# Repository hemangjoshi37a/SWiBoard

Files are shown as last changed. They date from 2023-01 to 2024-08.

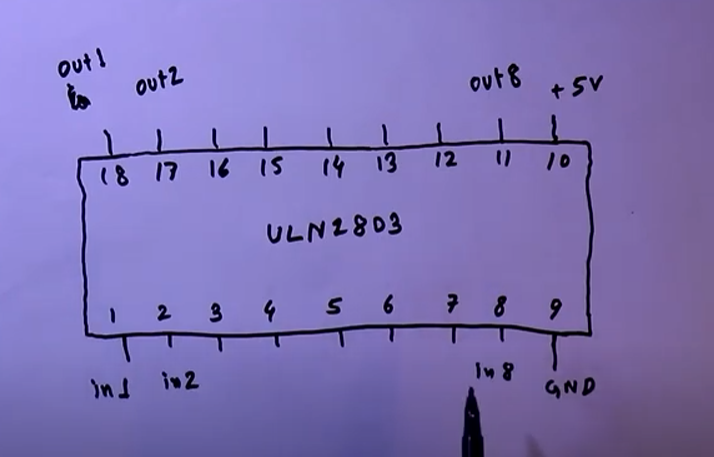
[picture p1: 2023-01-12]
ULN2803_PINOUT.PNG

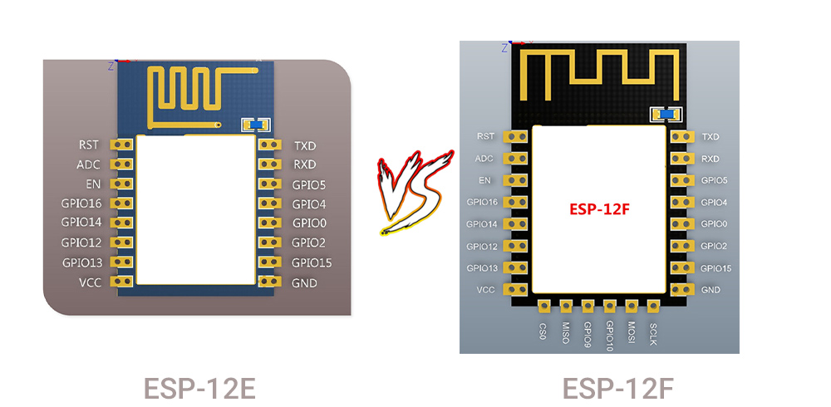
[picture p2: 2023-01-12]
ESP12F_VS_ESP12E_PINOUT.jpg

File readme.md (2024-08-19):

# 🏠 SWiBoard: Revolutionize Your Home with Smart WiFi Switch Control

  

> Transform your living space into a smart home paradise with SWiBoard - Where convenience meets innovation!

SWiBoard - Smart WiFi Switch Board Converter

## 🚀 Embrace the Future of Home Automation with SWiBoard

Are you ready to step into the future of home automation? SWiBoard is your gateway to a smarter, more connected living space. Our cutting-edge Tasmota IoT WiFi switch board converter seamlessly transforms your ordinary switches into powerful smart controls, putting the power of home automation right at your fingertips.

### 🌟 Unleash the Power of Smart Home Technology

- **Effortless Installation**: Upgrade your home without the hassle of complex rewiring
- **Global Control**: Manage your entire home from anywhere in the world with your smartphone
- **Voice-Activated Convenience**: Compatible with Amazon Alexa and Google Assistant for hands-free control
- **Versatile Connectivity**: Support for MQTT, HTTP, and more protocols ensures maximum compatibility
- **Budget-Friendly Innovation**: Experience the benefits of a smart home without breaking the bank

## 📱 SWiBoard Android App: Your Smart Home Command Center

Take charge of your smart home ecosystem with our intuitive, Flutter-powered Android app. Experience seamless control across all your devices with a user-friendly interface designed for both beginners and tech enthusiasts.

| Home Screen | Device Control | Settings | Customization | MQTT Setup |
|:-:|:-:|:-:|:-:|:-:|
| Home | Control | Settings | Customize | MQTT |

### 🛠️ Powerful Features at Your Fingertips

- **Centralized Device Management**: Control all your SWiBoard devices from a single, intuitive dashboard
- **Real-Time Responsiveness**: Experience instant status updates for precise control
- **User-Centric Design**: Navigate effortlessly with our thoughtfully crafted interface
- **Robust MQTT Integration**: Enjoy reliable, low-latency communication for seamless operation
- **Personalization Options**: Tailor your smart home experience with custom device names and icons

## 💡 Why SWiBoard is the Smart Choice for Your Home

1. **Seamless Integration**: Perfectly adapts to your existing electrical infrastructure
2. **Scalable Smart Home Solution**: Start small and expand your smart home ecosystem at your own pace
3. **Energy Optimization**: Monitor and reduce your power consumption for a greener home
4. **Enhanced Home Security**: Simulate occupancy by controlling lights remotely
5. **Future-Ready Technology**: Regular updates keep you at the forefront of smart home innovation

## 🔧 Technical Prowess Meets User-Friendly Design

- **Universal Compatibility**: Works flawlessly with most standard switch boxes
- **Reliable Connectivity**: Utilizes stable WiFi 2.4GHz technology
- **Flexible Power Options**: Supports AC 100-240V for global use
- **Cross-Platform App Support**: Compatible with Android 5.0+ and iOS 10.0+
- **Diverse Protocol Support**: Harness the power of MQTT, HTTP, and CoAP for ultimate flexibility

## 📦 Unboxing Your Smart Home Future

- SWiBoard WiFi Switch Converter: The heart of your smart home transformation
- Comprehensive Installation Guide: Step-by-step instructions for a smooth setup
- Mounting Hardware: Everything you need for a secure installation
- Professional-Grade Wire Connectors: Ensure safe and reliable electrical connections

## 🛠️ From Traditional to Smart: Your Installation Journey

1. Safety First: Power down at the circuit breaker
2. Out with the Old: Remove your existing switch plate
3. Smart Connections: Wire up your SWiBoard following our detailed diagram
4. Secure Integration: Mount SWiBoard firmly in your switch box
5. Power Up: Restore electricity and connect to your home WiFi
6. App Magic: Download the SWiBoard app and bring your smart switch to life!

## 📱 Embark on Your SWiBoard App Adventure

### Project Anatomy

```
swiboard/
├── lib/               # Core Dart code
│   ├── main.dart      # Application entry point
│   ├── screens/       # UI screen implementations
│   ├── widgets/       # Reusable UI components
│   └── services/      # Business logic and data management
├── android/           # Android-specific configurations
├── ios/               # iOS-specific setups
├── assets/            # Static resources (images, fonts)
└── test/              # Automated tests for robust performance
```

### Quick Start Guide

1. Prepare Your Environment: Ensure Flutter is properly installed
2. Clone the Innovation: `git clone https://github.com/hemangjoshi37a/swiboard.git`
3. Navigate to the Future: `cd swiboard`
4. Gather the Essentials: `flutter pub get`
5. Launch into Smart Home Control: `flutter run`

### Crafting Your Smart Home App

- For Android Enthusiasts: `flutter build apk`
- For iOS Aficionados: `flutter build ios` (Xcode required on macOS)

## 🔗 Your Gateway to Smart Living

- [🛒 Acquire SWiBoard](https://hjlabs.in/product/swiboard-wifi-switch-board-iot-device/)
- [📱 SWiBoard App Download](https://play.google.com/store/apps/details?id=in.hjlabs.swiboard)
- [🎨 Explore SWiBoard's 3D Design](https://grabcad.com/library/swiboard-tasmota-iot-wifi-switch-board-converter-1)
- [🎥 Witness SWiBoard in Action](https://youtu.be/BrakSGmQZB8)

## 📫 Connect with the Mastermind Behind SWiBoard

[](https://wa.me/917016525813) &nbsp;
[](https://t.me/hjlabs) &nbsp;
[](mailto:hemangjoshi37a@gmail.com) &nbsp;
[](https://www.linkedin.com/in/hemang-joshi-046746aa) &nbsp;
[](https://www.facebook.com/hemangjoshi37) &nbsp;
[](https://twitter.com/HemangJ81509525) &nbsp;
[](https://www.tumblr.com/blog/hemangjoshi37a-blog) &nbsp;
[](https://stackoverflow.com/users/8090050/hemang-joshi) &nbsp;
[](https://www.instagram.com/hemangjoshi37) &nbsp;
[](https://in.pinterest.com/hemangjoshi37a) &nbsp;
[](http://hemangjoshi.blogspot.com) &nbsp;
[](https://hjlabs.in/) &nbsp;
[](https://gitlab.com/hemangjoshi37a) &nbsp;

## 🚀 Dive into a World of Innovation

Explore more groundbreaking projects that are shaping the future of technology:

- [pyPortMan](https://github.com/hemangjoshi37a/pyPortMan): Revolutionizing port management
- [transformers_stock_prediction](https://github.com/hemangjoshi37a/transformers_stock_prediction): AI-powered stock market insights
- [TrendMaster](https://github.com/hemangjoshi37a/TrendMaster): Stay ahead of market trends
- [hjAlgos_notebooks](https://github.com/hemangjoshi37a/hjAlgos_notebooks): A treasure trove of algorithmic wisdom
- [AutoCut](https://github.com/hemangjoshi37a/AutoCut): Streamlining video editing workflows
- [My_Projects](https://github.com/hemangjoshi37a/My_Projects): A showcase of diverse tech innovations
- [Arduino and ESP8266 Wonders](https://github.com/hemangjoshi37a/my_Arduino): Pushing the boundaries of IoT
- [TelegramTradeMsgBacktestML](https://github.com/hemangjoshi37a/TelegramTradeMsgBacktestML): Where finance meets machine learning

## 🤝 Join the Smart Home Revolution

Your insights and contributions can help shape the future of SWiBoard! Whether you're squashing bugs, enhancing documentation, or dreaming up new features, your input is invaluable. Don't hesitate to submit pull requests or raise issues for any improvements you envision.

## 📄 Open Source Commitment

SWiBoard is proudly open source, licensed under the MIT License. For full details, refer to the [LICENSE](LICENSE) file in our repository.

---

<p align="center">
  <i>Embark on your smart home journey with SWiBoard - Where every switch is a step into the future!</i>
</p>

<p align="center">
  <a href="https://hjlabs.in/product/swiboard-wifi-switch-board-iot-device/">🏠 Acquire SWiBoard</a> •
  <a href="https://play.google.com/store/apps/details?id=in.hjlabs.swiboard">📱 Get the App</a> •
  <a href="https://github.com/hemangjoshi37a/swiboard/issues">🐛 Report Issues</a> •
  <a href="https://github.com/hemangjoshi37a/swiboard/issues">✨ Suggest Features</a>
</p>

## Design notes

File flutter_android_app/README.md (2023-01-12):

# swiboard

Your Own WiFi Switch Board Converter

The SWiBoard is a versatile Tasmota IoT WiFi switch board converter that allows you to easily convert your traditional switches into smart, WiFi-enabled controls. With this device, you can control your lights and appliances remotely using your smartphone or voice commands through Amazon Alexa or Google Assistant. Its compact design and easy installation make it an ideal solution for both residential and commercial settings. Additionally, the SWiBoard supports various protocols such as MQTT, HTTP, and more, making it compatible with a wide range of home automation platforms. With the SWiBoard, you can enjoy the convenience and flexibility of smart home technology without the need for expensive and complex rewiring.

- [Buy Now on hjLabs.in](https://hjlabs.in/product/swiboard-wifi-switch-board-iot-device/)
- [SWiBoard App :Tasmota MQTT Control](https://play.google.com/store/apps/details?id=in.hjlabs.swiboard)
- [SWiBoard 3D Design on GrabCAD](https://grabcad.com/library/swiboard-tasmota-iot-wifi-switch-board-converter-1)

## Social Media :
*  [WhatsApp/917016525813](https://wa.me/917016525813)
*  [Telegram/hjlabs](https://t.me/hjlabs)
* [ Gmail/hemangjoshi37a@gmail.com](mailto:hemangjoshi37a@gmail.com)
* [ Facebook/hemangjoshi37](https://www.facebook.com/hemangjoshi37/)
* [ Twitter/HemangJ81509525](https://twitter.com/HemangJ81509525)
*  [LinkedIn/hemang-joshi-046746aa](https://www.linkedin.com/in/hemang-joshi-046746aa/)
*  [Tumblr/hemangjoshi37a-blog](https://www.tumblr.com/blog/hemangjoshi37a-blog)
*  [Pinterest/hemangjoshi37a](https://in.pinterest.com/hemangjoshi37a/)
*  [Blogger/hemangjoshi](http://hemangjoshi.blogspot.com/)
*  [Instagram/hemangjoshi37](https://www.instagram.com/hemangjoshi37/)

## Checkout Cool GitHub Other Repositories:
- [pyPortMan](https://github.com/hemangjoshi37a/pyPortMan)
- [transformers_stock_prediction](https://github.com/hemangjoshi37a/transformers_stock_prediction)
- [TrendMaster](https://github.com/hemangjoshi37a/TrendMaster)
- [hjAlgos_notebooks](https://github.com/hemangjoshi37a/hjAlgos_notebooks)
- [AutoCut](https://github.com/hemangjoshi37a/AutoCut)
- [My_Projects](https://github.com/hemangjoshi37a/My_Projects)
- [Cool Arduino and ESP8266 or NodeMCU Projects](https://github.com/hemangjoshi37a/my_Arduino)
- [Telegram Trade Msg Backtest ML](https://github.com/hemangjoshi37a/TelegramTradeMsgBacktestML)

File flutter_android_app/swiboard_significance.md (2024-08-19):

# SWiBoard - A Tasmota MQTT5 Flutter Firebase App

Your Own WiFi Switch Board

## The significance for SWiBoard App

### Why App when I have web access to tasmota device?

- For the most use cases one might not be under the same wifi network. And need remote access to the device from internet.

### I can easily forward port from my local network and can access it from internet. Then why App?

- One might not have access to static IP considering where one is living or may be very costly to have static IP. So we need MQTT5 for connecting device with internet.

### There are already many apps available on playstore for tasmota then why SWiBoard?

- Most if not all of them only use web socket to connect to tasmota device and not MQTT, and that's why they are not suitable for use from internet connection. Also configuring all the apps with tasmota device is quite tricky in some cases. But in SWiBoard you need to onyl enter the device topic of your tasmota device and it automatically configures your app and adds the device and UI componets of the configures device like switches and sliders and color selector etc.

- Also nice to have is we are using google firebase databse to store the configurations of the users so that if they somehow uninstall the app or change the device that all they need to do is just install the app and login with google account to get all the configuration back and don't need to reconfigure all the devices.

## Also in near future we are trying to give as many options as possible in the app to configure the device using MQTT5 to configure from the internet

## Here is the link to The app : [SWiBoard :Tasmota MQTT Control](https://play.google.com/store/apps/details?id=in.hjlabs.swiboard)

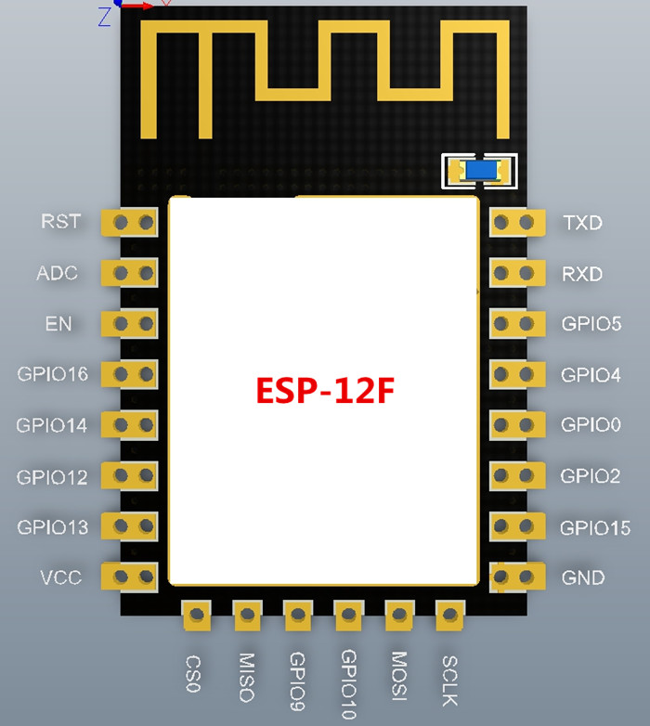
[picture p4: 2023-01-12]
esp12f_pinout.jpg

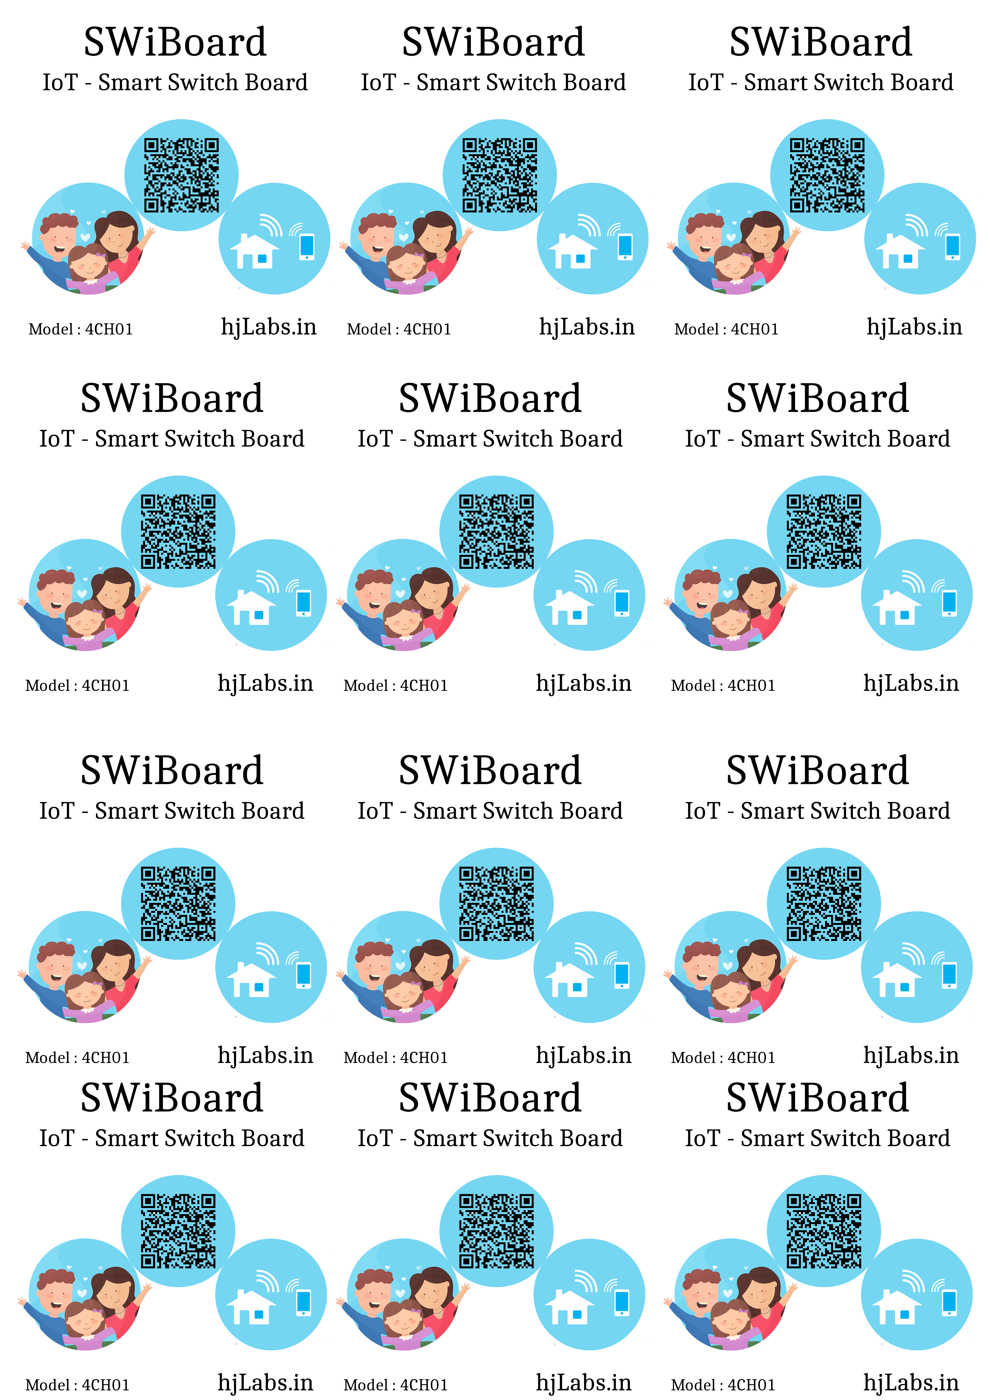
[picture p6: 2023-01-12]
Cover_sticker.png

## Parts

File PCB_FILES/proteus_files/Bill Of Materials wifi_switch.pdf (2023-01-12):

# Bill Of Materials for wifi_switch

Design Title | wifi_switch

## Author Document Number Revision

Design Created | 11 July 2022

## Design Last Modified 02 November 2022 Total Parts In Design 36

## 0Modules

Quantity | References | Value | PCBPackage | StockCode | Unit Cost
Sub-totals: | £0.00

## 2Capacitors

Quantity | References | Value | PCBPackage | StockCode | Unit Cost
2 | C1-C2 | 0.1u | CAPC3216X140 | Digikey 311-1179-1- ND
Sub-totals: | £0.00

## 8Resistors

Quantity | References | Value | PCBPackage | StockCode | Unit Cost
4 | R1_470,R3_470,R5_470, R7_470 | 470 | RESC5025X65 | Digikey P470WCT-ND | £2.70
4 | R2_120,R4_120,R6_120, R8_120 | 120Ohm | RESC5025X65 | Digikey P120WTR-ND | £2.70
Sub-totals: | £21.60

## 0Integrated Circuits

Quantity | References | Value | PCBPackage | StockCode | Unit Cost
Sub-totals: | £0.00

## 4Transistors

Quantity | References | Value | PCBPackage | StockCode | Unit Cost
4 | Q1-Q4 | 2N3904 | TO92127P495H4953 | | £3.00
Sub-totals: | £12.00

## 0Diodes

Quantity | References | Value | PCBPackage | StockCode | Unit Cost
Sub-totals: | £0.00

## 22Miscellaneous

Quantity | References | Value | PCBPackage | StockCode | Unit Cost
1 | 12PIN_TERMINAL | TBLOCK-M12 | TBLOCK-M12 | | £88.00
1 | DC_JACK | RAPC722X | RAPC722X | | £8.40
1 | DISPLAY | CONN-SIL4 | CONN-SIL4 | | £0.90
1 | ESP | ESP-12F | ESP-12F | | £102.00
4 | OP1-OP4 | PC817 | DIL04 | | £6.50
4 | PN1-PN4 | 1N4007SMD | C1206 | | £2.00
1 | PROG | CONN-SIL6 | CONN-SIL6 | | £1.35
1 | RESET | CONN-SIL2 | CONN-SIL2 | | £0.45
4 | RL1-RL4 | G5CLE-1- DC12 | RLY-OMRON-C4 | | £26.00
1 | RX | JUMPER | CONN-SIL2 | | £0.85
2 | SMPS_5V_GND,SMPS_L_N | TBLOCK-I2 | TBLOCK-I2 | | £5.00
1 | VREG | AMS1117 | AMS1117
Sub-totals: | £349.95
Totals: | | | | | £383.55

07 November 2022 05:19:19

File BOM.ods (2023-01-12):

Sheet: ESP8266_4Channel
No. | Name | Rate | Qty | Total | LINK1 | LINK2 | LINK3
1 | NodeMCU | 189 | 1 | 189 | ElectronicsComp (https://www.electronicscomp.com/nodemcu-esp8266-wifi-development-board) | ktron (https://www.ktron.in/product/nodemcu-esp8266-ch340g-wifi-development-board/?hsa_acc=6332829093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) | quartzcomponents (https://quartzcomponents.com/products/esp8266-ch340-nodemcu-wi-fi-module?variant=39527216840888&currency=INR)
2 | 4 channel relay | 140 | 1 | 140 | electronicscomp (https://www.electronicscomp.com/4-channel-5v-relay-module-with-optocoupler) | quartzcomponents (https://quartzcomponents.com/products/four-channel-relay-module-made-in-india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) | compoindia (https://compoindia.com/product/5v-4-channel-relay-module/)
3 | Din Rail x12 | 20 | 1 | 20
4 | SMPS 5V 2A | 120 | 1 | 120 | quartzcomponents (https://quartzcomponents.com/products/5v-2a-circuit-switch-power-supply-module-smps-pcb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) | hnhcart (https://www.hnhcart.com/products/220v-ac-to-5v-2-4a-dc-smps-power-supply-circuit-board) | electronicscomp (https://www.electronicscomp.com/precision-5v-700ma-3.5w-isolation-power-supply-module-ac-dc-step-down-module-220v-to-5v) | hnhcart (https://www.hnhcart.com/products/5v-2a-power-supply-with-double-usb-output-1)
5 | plastic box | 30 | 1 | 30
6 | Wire (3 Meter) | 30 | 1 | 30
7 | SSD1306 | 180 | 1 | 180 | electronicscomp (https://www.electronicscomp.com/0.96-inch-i2c-iic-128x64-oled-display-module-4-pin-blue-color) | ktron (https://www.ktron.in/product/oled-display-i2c-0-96-inch/?hsa_acc=6332829093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) | quartzcomponents (https://quartzcomponents.com/products/oled-display-0-96-inch-i2c-interface-4-pin-blue-ssd1306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) | ktron (https://www.ktron.in/product/0-96-inch-oled-display-yellow-blue-i2c-iic/?hsa_acc=6332829093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) | robotrack (https://www.robotrack.co.in/index.php?route=product/product&product_id=386&description=true)
8 |  |  |  | 0
9 |  |  |  | 0
10 |  |  |  | 0
 |  |  | Total | 709
 | WO display |  |  | 529

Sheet: ESP32_8Channel
No. | Name | Rate | Qty | Total | LINK1 | LINK2 | LINK3
1 | ESP32 Devkit | 360 | 1 | 360 | electronicscomp (https://www.electronicscomp.com/esp32-development-board-with-wifi-bluetooth-india) | ktron (https://www.ktron.in/product/esp32-development-board/?hsa_acc=6332829093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) | robu (https://robu.in/product/esp-wroom-32-esp32-wifi-bt-ble-mcu-module/) | robotrack (https://www.robotrack.co.in/index.php?route=product/product&product_id=73&description=true) | quartzcomponents (https://quartzcomponents.com/products/esp32-development-board-wifi-bluetooth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) | hnhcart (https://www.hnhcart.com/products/copy-of-espressif-esp32-wroom-32-module) | robu (https://robu.in/product/esp-wroom-32-wifi-bluetooth-networking-smart-component-development-board/) | ktron (https://www.ktron.in/product/esp32-devkitc-with-ufl-connector/?hsa_acc=6332829093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)
2 | 8 channel 5V relay | 237 | 1 | 237 | electronicscomp (https://www.electronicscomp.com/8-channel-5v-relay-module-with-optocoupler) | robu (https://robu.in/product/8-channel-isolated-5v-10a-relay-module-opto-coupler-for-arduino-pic-avr-dsp-arm/) | compoindia (https://compoindia.com/product/8-channel-isolated-5v-10a-relay-module-opto-coupler-for-arduino-pic-avr-dsp-arm/) | hnhcart (https://www.hnhcart.com/products/8-channel-5v-10a-relay-module-with-optocoupler) | robotrack (https://www.robotrack.co.in/index.php?route=product/product&product_id=153&description=true) | quartzcomponents (https://quartzcomponents.com/products/8-channel-5v-relay-module-with-optocoupler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) | makerbazar (https://makerbazar.in/products/8-channel-5v-10a-relay-module-with-optocoupler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)
3 | Din Rail x12 | 20 | 1 | 20
4 | SMPS 5V 2A | 120 | 1 | 120 | quartzcomponents (https://quartzcomponents.com/products/5v-2a-circuit-switch-power-supply-module-smps-pcb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) | hnhcart (https://www.hnhcart.com/products/220v-ac-to-5v-2-4a-dc-smps-power-supply-circuit-board) | electronicscomp (https://www.electronicscomp.com/precision-5v-700ma-3.5w-isolation-power-supply-module-ac-dc-step-down-module-220v-to-5v) | hnhcart (https://www.hnhcart.com/products/5v-2a-power-supply-with-double-usb-output-1)
5 | plastic box | 30 | 1 | 30
6 | Wire (3 Meter) | 30 | 1 | 30
7 | SSD1306 | 180 | 1 | 180 | electronicscomp (https://www.electronicscomp.com/0.96-inch-i2c-iic-128x64-oled-display-module-4-pin-blue-color) | ktron (https://www.ktron.in/product/oled-display-i2c-0-96-inch/?hsa_acc=6332829093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) | quartzcomponents (https://quartzcomponents.com/products/oled-display-0-96-inch-i2c-interface-4-pin-blue-ssd1306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) | ktron (https://www.ktron.in/product/0-96-inch-oled-display-yellow-blue-i2c-iic/?hsa_acc=6332829093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) | robotrack (https://www.robotrack.co.in/index.php?route=product/product&product_id=386&description=true)
8 |  |  |  | 0
9 |  |  |  | 0
10 |  |  |  | 0
 |  |  | Total | 977
 |  |  |  |  |  |  | Min | Max | Unit Price
 |  |  |  |  |  |  | 1 | 4 | ₹431.60
 |  |  |  |  |  |  | 5 | 9 | ₹418.65
 |  |  |  |  |  |  | 10 | 19 | ₹405.70
 |  |  |  |  |  |  | 20 | 49 | ₹397.07
 |  |  |  |  |  |  | 50 | And more. | ₹392.76
 |  |  |  |  |  |  | Weight | 13 g

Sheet: ESP8266_4Channel_RAW
No. | Name | Rate | Qty | Total | LINK1 | LINK2 | LINK3
1 | Relay 5V 10A | 17.5 | 4 | 70 | electronicscomp (https://www.electronicscomp.com/5v-10a-pcb-relay) | ktron (https://www.ktron.in/product/5v-10a-relay-t73-sugar-cube/?hsa_acc=6332829093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) | lakhielectronics (https://lakhielectronics.com/switches-and-relays/224-5v-10a-spdt-sugar-cube-relay-switch-pcb-mount.html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)
2 | ESP12F | 100 | 1 | 100 | electronicscomp (https://www.electronicscomp.com/esp-12f-esp8266-wifi-wireless-module) | ktron (https://www.ktron.in/product/esp8266-esp-12f-wifi-module/?hsa_acc=6332829093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) | quartzcomponents (https://quartzcomponents.com/products/esp-12f-esp8266-wifi-wireless?variant=40715088232632&currency=INR)
3 | 12 Pin 5.08mm Pitch Pluggable Screw Terminal Block | 69 | 1 | 69 | robu (https://robu.in/product/12-pin-5-08mm-pitch-pluggable-screw-terminal-block/) | electronicscomp (https://www.electronicscomp.com/6-pin-5.08mm-pitch-pluggable-screw-terminal-block)
4 | PCB | 30 | 1 | 30
5 | SMPS 5V 2A | 120 | 1 | 120 | quartzcomponents (https://quartzcomponents.com/products/5v-2a-circuit-switch-power-supply-module-smps-pcb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) | hnhcart (https://www.hnhcart.com/products/220v-ac-to-5v-2-4a-dc-smps-power-supply-circuit-board) | electronicscomp (https://www.electronicscomp.com/precision-5v-700ma-3.5w-isolation-power-supply-module-ac-dc-step-down-module-220v-to-5v) | hnhcart (https://www.hnhcart.com/products/5v-2a-power-supply-with-double-usb-output-1)
6 | Relay Driver ULN2803 | 22 | 1 | 22 | electronicscomp (https://www.electronicscomp.com/uln2803-ic) | robu (https://robu.in/product/uln-2803/) | hnhcart (https://www.hnhcart.com/products/uln2803-eight-darlington-arrays)
7 | OPTO PC817 | 4 | 4 | 16 | electronicscomp (https://www.electronicscomp.com/pc817-optocoupler) | ktron (https://www.ktron.in/product/pc817-dip-4-optocoupler-sharp/?hsa_acc=6332829093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) | hnhcart (https://www.hnhcart.com/products/pc817-transistor-output-optocoupler) | robu (https://robu.in/product/pc817-dip-4-transistor-output-optocoupler-pack-of-5-ics/) | makerbazar (https://makerbazar.in/products/pc817-dip-4-transistor-output-optocoupler?variant=42963908329712&currency=INR)
8 | Resistor 220Ω | 0.2 | 4 | 0.8 | hnhcart (https://www.hnhcart.com/products/220-ohm-resistor-1-8-watt-pack-of-50) | electronicscomp (https://www.electronicscomp.com/220-ohm-resistance) | robu (https://robu.in/product/220-ohm-resistor-0-25w-metal-film-pack-of-100/)
9 | LED 5mm | 1.3 | 4 | 5.2 | robu (https://robu.in/product/5mm-dip-led-white-50-pcs/) | electronicscomp (https://www.electronicscomp.com/blue-led-5mm-diffused-india) | electronicscomp (https://www.electronicscomp.com/green-led-5mm-diffused-india) | robu (https://robu.in/product/orange-100pcs-5-colors-f3mm-led-kit/)
10 | Acrylic Box | 50 | 1 | 50
11
12
 |  |  | Total | 483
 | profit from raw |  |  | 46

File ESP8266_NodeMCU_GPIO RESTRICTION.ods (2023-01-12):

GPIO RESTRICTION
NodeMCU Labelled Pin (https://techtutorialsx.com/2017/04/02/esp8266-nodemcu-pin-mappings/) | GPIO# | Function | State | Restrictions
D3 | 0 | Boot mode select | 3.3V | No Hi-Z
D10 | 1 | TX0 | - | Not usable during Serial transmission - Boot will fail if LOW at boot
D4 | 2 | Boot mode select TX1 | 3.3V (boot only) | Don’t connect to ground at boot time - boot will fail. Sends debug data at boot time
D9 | 3 | RX0 | - | Not usable during Serial transmission
D2 | 4 | SDA (I²C) | - | -
D1 | 5 | SCL (I²C) | - | -
x | 11 | Flash connection | x | Not usable, and not broken out
D6 | 12 | MISO (SPI) | - | -
D7 | 13 | MOSI (SPI) | - | -
D5 | 14 | SCK (SPI) | - | -
D8 | 15 | SS (SPI) | 0V | Pull-up resistor not usable (extern pull down resistor)
D0 | 16 | Wake up from sleep | - | No pull-up resistor, but pull-down instead Should be connected to RST to wake up
x | 6 - 8 | Flash connection | x | Not usable, and not broken out
x | 9, 10 | Flash connection * |  | Only available on the ESP8285

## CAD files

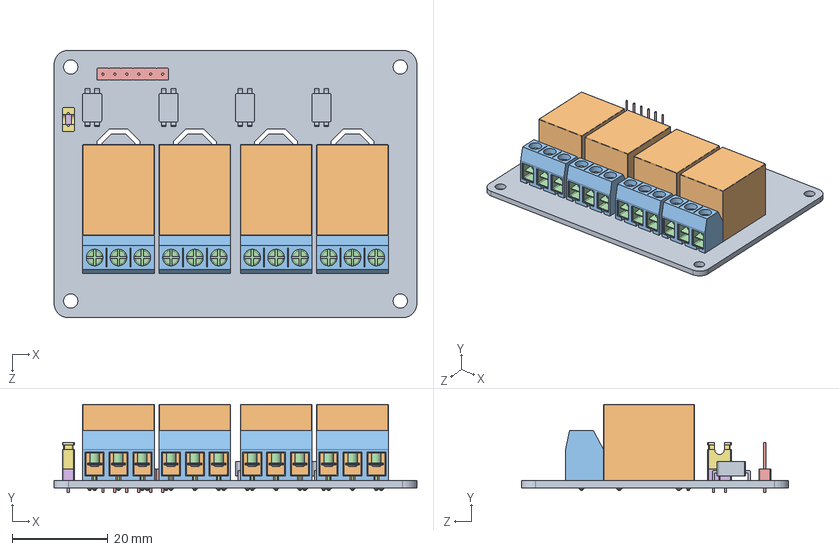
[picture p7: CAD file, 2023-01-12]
4-channel-relay-module-5v-no-name-1.snapshot.2/4 Channel No Name Relay Parts/Relay - 4 Ch - 5v Montaj.SLDASM
76.0 x 18.5 x 56.0 mm
4 Ch - 5v Relay Board
Relay Body x 4
Clamp Body x 4
Metal Clamp Part x 12
6 Header
2 Header
Jumper

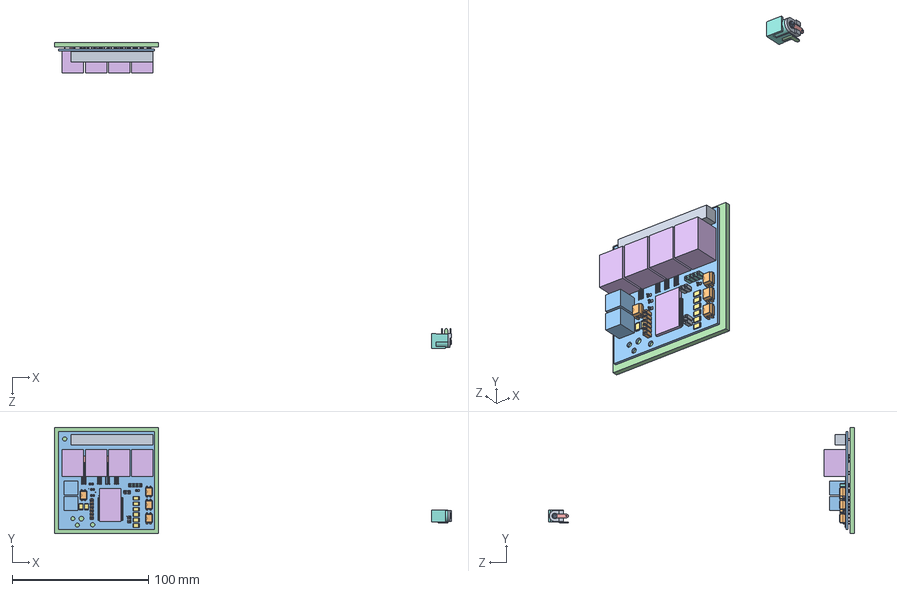
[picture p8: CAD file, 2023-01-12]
PCB_FILES_V2/BOX_CAD/bottom_plate.SLDASM
291.5 x 78.0 x 224.4 mm
Body_1.STEP
Pin_1.STEP
Pin_2.STEP
Pin_3.STEP
Pin_4.STEP
Pin_5.STEP
Pin_6.STEP
Pin_7.STEP
Pin_8.STEP
Pin_9.STEP
Pin_10.STEP
Pin_11.STEP
Pin_12.STEP
Body_1-0.STEP
Pin_1-1.STEP
Pin_2-2.STEP
Pin_3-3.STEP
Pin_4-4.STEP
Pin_5-5.STEP
Pin_6-6.STEP
Pin_7-7.STEP
Pin_8-8.STEP
Pin_9-9.STEP
Pin_10-10.STEP
Pin_11-11.STEP
Pin_12-12.STEP
Pin_13.STEP
Pin_14.STEP
Pin_15.STEP
Pin_16.STEP
Body_1-13.STEP x 8
Pin_1-14.STEP x 8
Pin_2-15.STEP x 8
Body_1-16.STEP x 4
Body_1-17.STEP x 2
Pin_1-18.STEP x 2
Pin_2-19.STEP x 2
1.STEP x 4
2.STEP x 4
Body_1-21.STEP
=_[0_1_1_3].STEP
=_[0_1_1_4].STEP
=_[0_1_1_5].STEP
=_[0_1_1_6].STEP
=_[0_1_1_7].STEP
=_[0_1_1_8].STEP
=_[0_1_1_9].STEP
=_[0_1_1_10].STEP
Body_1-22.STEP x 2
=_[0_1_1_3]-23.STEP x 4
=_[0_1_1_4]-24.STEP x 4
=_[0_1_1_5]-25.STEP x 4
=_[0_1_1_6]-26.STEP x 4
=_[0_1_1_7]-27.STEP x 4
Body_1-28.STEP x 4
Pin_1-29.STEP x 4
Pin_2-30.STEP x 4
Body_1-31.STEP
Layer_1.STEP
Part120^Assem64

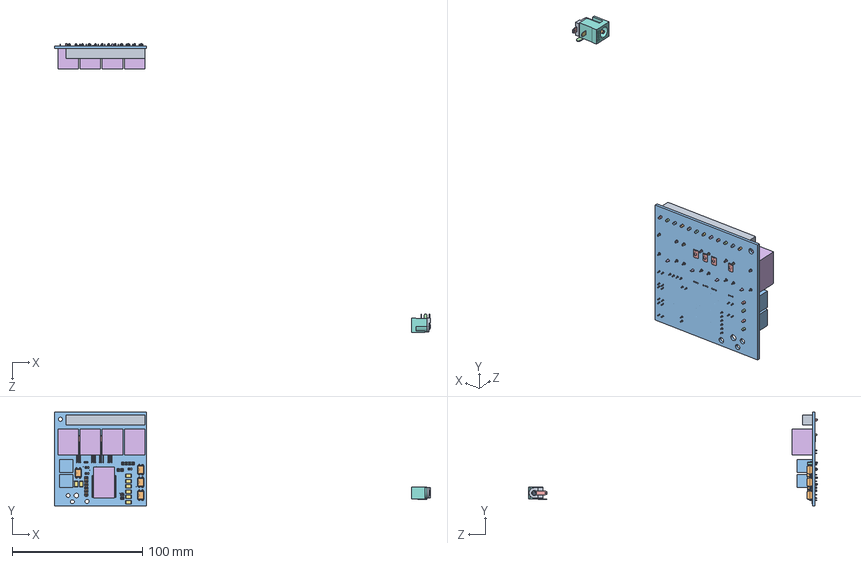
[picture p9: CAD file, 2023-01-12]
PCB_FILES/BOX_CAD/wifi_switch.SLDASM
288.5 x 72.0 x 221.8 mm
Body_1.STEP
Pin_1.STEP
Pin_2.STEP
Pin_3.STEP
Pin_4.STEP
Pin_5.STEP
Pin_6.STEP
Pin_7.STEP
Pin_8.STEP
Pin_9.STEP
Pin_10.STEP
Pin_11.STEP
Pin_12.STEP
Body_1-0.STEP
Pin_1-1.STEP
Pin_2-2.STEP
Pin_3-3.STEP
Pin_4-4.STEP
Pin_5-5.STEP
Pin_6-6.STEP
Pin_7-7.STEP
Pin_8-8.STEP
Pin_9-9.STEP
Pin_10-10.STEP
Pin_11-11.STEP
Pin_12-12.STEP
Pin_13.STEP
Pin_14.STEP
Pin_15.STEP
Pin_16.STEP
Body_1-13.STEP x 8
Pin_1-14.STEP x 8
Pin_2-15.STEP x 8
Body_1-16.STEP x 4
Body_1-17.STEP x 2
Pin_1-18.STEP x 2
Pin_2-19.STEP x 2
1.STEP x 4
2.STEP x 4
Body_1-21.STEP
=_[0_1_1_3].STEP
=_[0_1_1_4].STEP
=_[0_1_1_5].STEP
=_[0_1_1_6].STEP
=_[0_1_1_7].STEP
=_[0_1_1_8].STEP
=_[0_1_1_9].STEP
=_[0_1_1_10].STEP
Body_1-22.STEP x 2
=_[0_1_1_3]-23.STEP x 4
=_[0_1_1_4]-24.STEP x 4
=_[0_1_1_5]-25.STEP x 4
=_[0_1_1_6]-26.STEP x 4
=_[0_1_1_7]-27.STEP x 4
Body_1-28.STEP x 4
Pin_1-29.STEP x 4
Pin_2-30.STEP x 4
Body_1-31.STEP
Layer_1.STEP

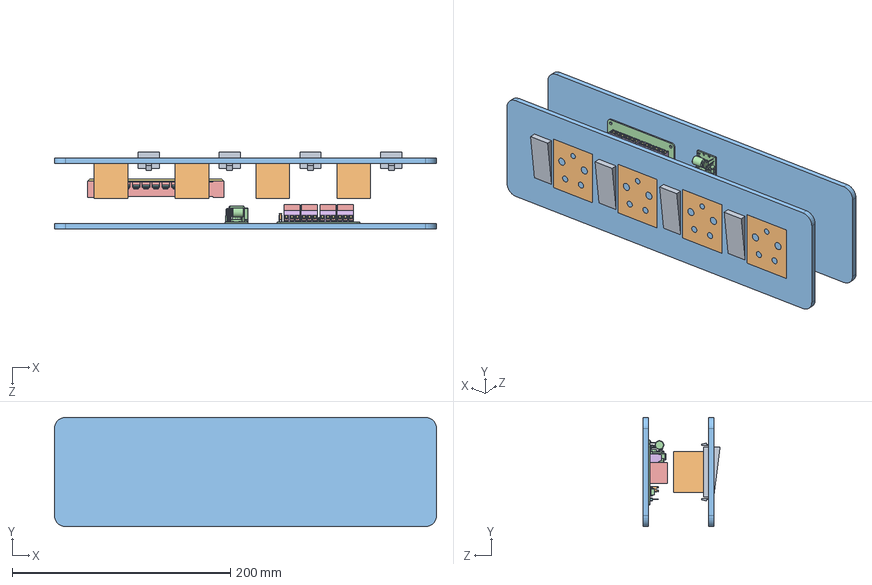
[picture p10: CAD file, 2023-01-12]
wifi_switch.SLDASM
350.0 x 100.0 x 70.8 mm
switch x 4
plug_socket x 4
4 Ch - 5v Relay Board
Relay Body x 4
Clamp Body x 4
Metal Clamp Part x 12
6 Header
2 Header
Jumper
back_plate
220ACto5VDC
Block, Terminal Block, 12 Positions, Dual Rows Covered, 600V 15A , Configurable
Conducting Strip, Terminal Block, 12 Positions, Dual Rows Covered, 600V 15A , Configurable x 11
Cover, Terminal Block, 12 Positions, Dual Rows Covered, 600V 15A , Configurable
Terminal Plate, Terminal Block, 12 Positions, Dual Rows Covered, 600V 15A , Configurable x 22

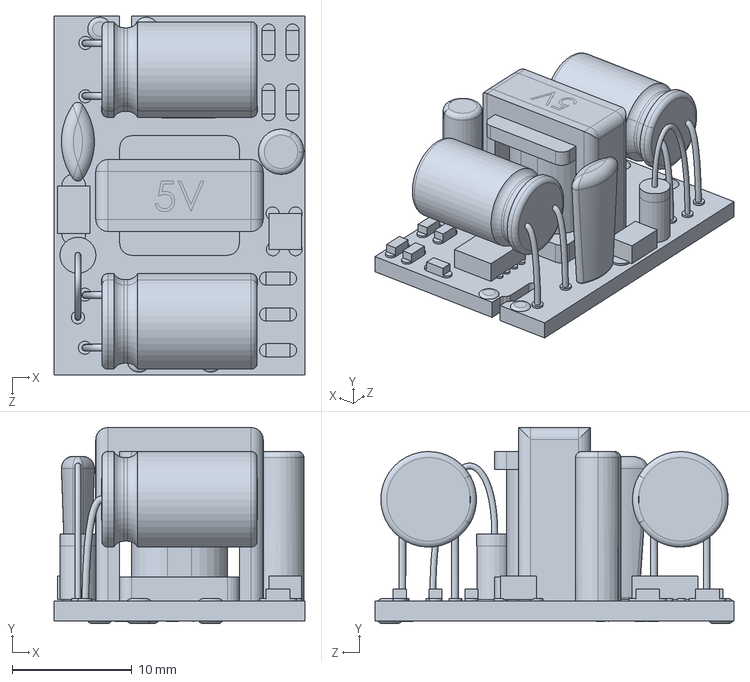
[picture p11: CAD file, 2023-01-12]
220ACto5VDC.SLDPRT
21.0 x 16.4 x 30.0 mm

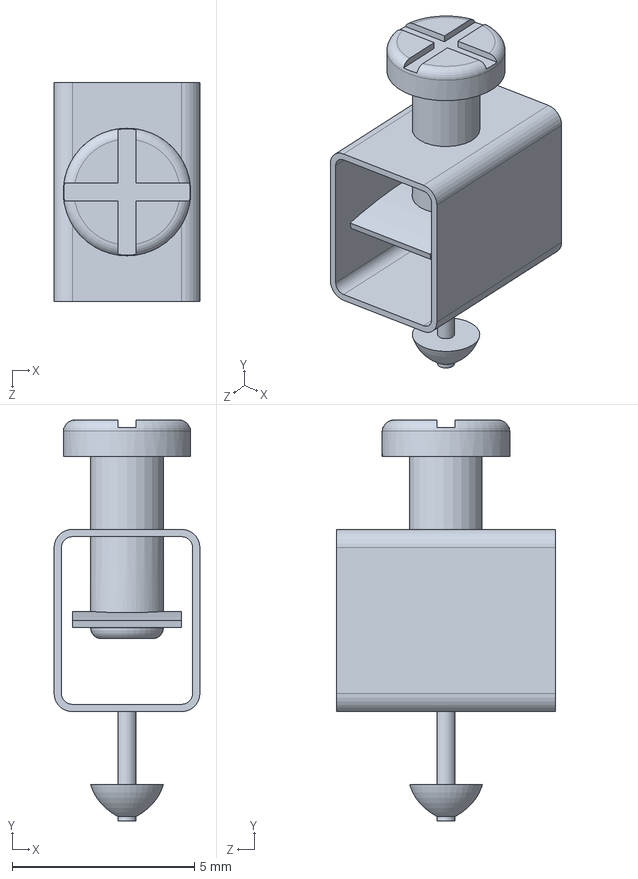
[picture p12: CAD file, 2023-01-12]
4-channel-relay-module-5v-no-name-1.snapshot.2/4 Channel No Name Relay Parts/Metal Clamp Part.SLDPRT
4.00 x 11.0 x 6.00 mm

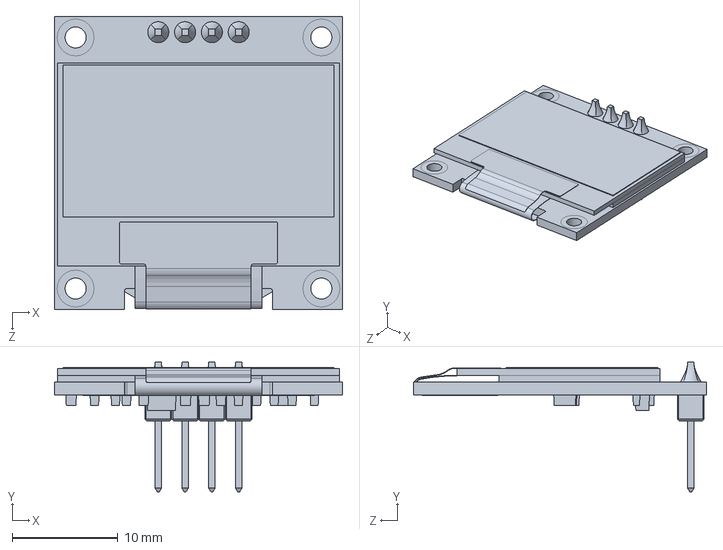
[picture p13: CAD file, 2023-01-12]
PCB_FILES_V2/BOX_CAD/OLED TFT 0.96 inch 64x128 monochrome.SLDPRT
27.3 x 12.3 x 27.8 mm

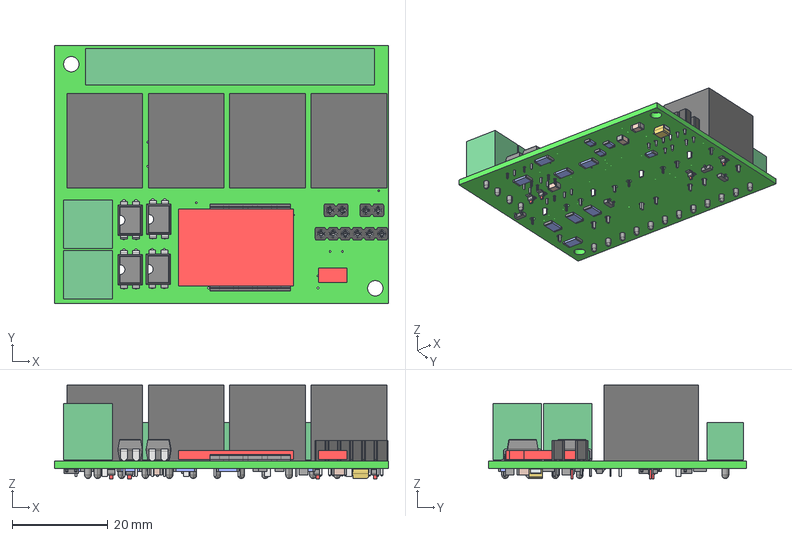
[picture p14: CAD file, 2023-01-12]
PCB_FILES_V2/proteus_files/wifi_switch.STEP
69.8 x 53.8 x 19.6 mm
Layer_1
Pin_1 x 27
Pin_2 x 27
Pin_3 x 6
Pin_4 x 2
Pin_5 x 2
Pin_6 x 2
Pin_7 x 2
Pin_8 x 2
Pin_9 x 2
Pin_10 x 2
Pin_11 x 2
Pin_12 x 2
Pin_13
Pin_14
Pin_15
Pin_16
=>[0:1:1:2]
=>[0:1:1:3]
=>[0:1:1:4]

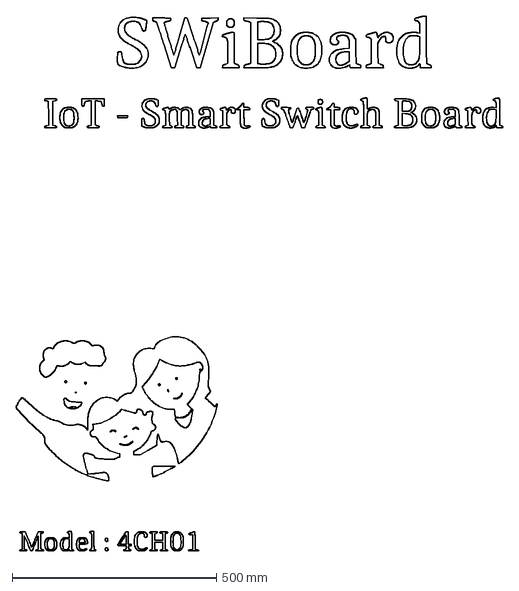
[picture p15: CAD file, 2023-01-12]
SWiBoard_sticker_design_DXF/#Cover_sticker_single.dxf
1192.0 x 1310.9 mm

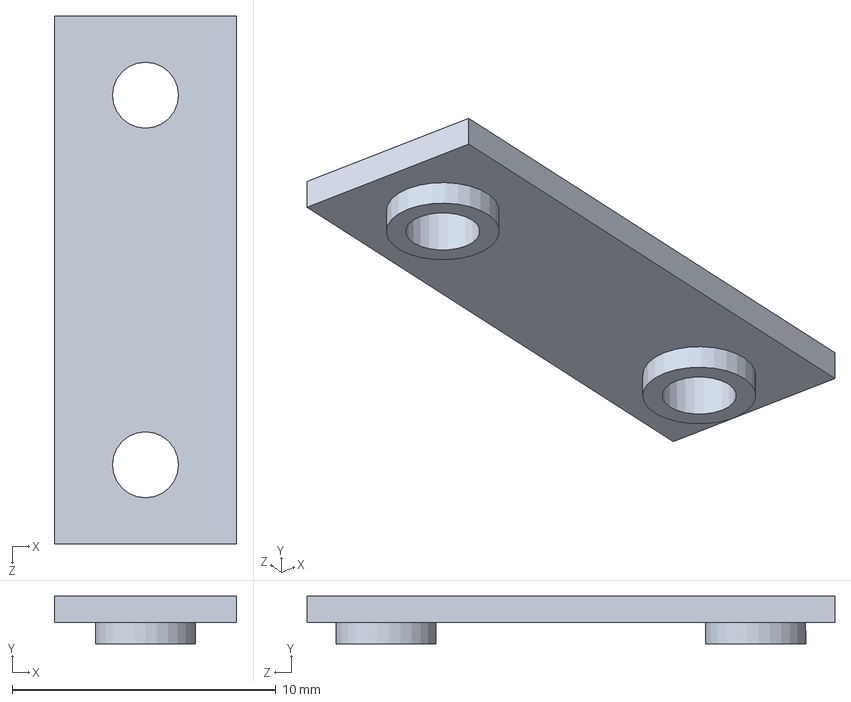
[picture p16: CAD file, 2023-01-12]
terminal-block-12-positions-dual-rows-covered-600v-15a-configurable-1.snapshot.2/Conducting Strip, Terminal Block, 12 Positions, Dual Rows Covered, 600V 15A , Configurable.SLDPRT
6.90 x 1.80 x 20.0 mm

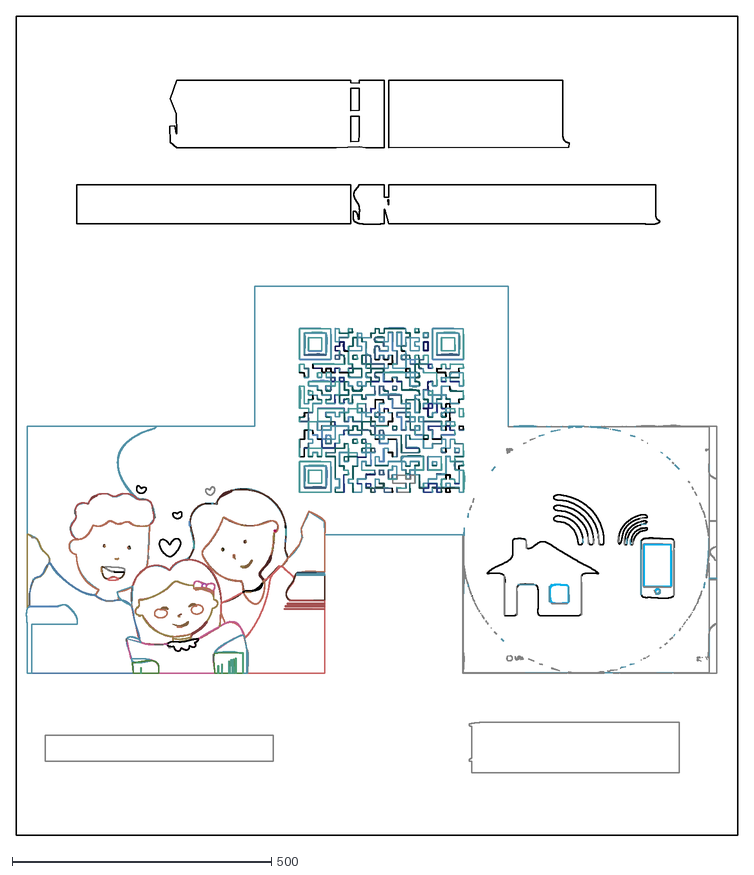
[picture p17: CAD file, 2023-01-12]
SWiBoard_sticker_design_DXF/AnyConv.com__Cover_sticker_single.dxf
1391.0 x 1579.0

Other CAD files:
PCB_FILES/BOX_CAD/back_plate.SLDPRT
PCB_FILES/wifi_switch.STEP
PCB_FILES_V2/wifi_switch.STEP
Part3.SLDPRT
PCB_FILES/BOX_CAD/top_plate.SLDPRT
4-channel-relay-module-5v-no-name-1.snapshot.2/4 Channel No Name Relay Parts/2 Header.SLDPRT
4-channel-relay-module-5v-no-name-1.snapshot.2/4 Channel No Name Relay Parts/4 Ch - 5v Relay Board.SLDPRT
4-channel-relay-module-5v-no-name-1.snapshot.2/4 Channel No Name Relay Parts/6 Header.SLDPRT
4-channel-relay-module-5v-no-name-1.snapshot.2/4 Channel No Name Relay Parts/Clamp Body.SLDPRT
4-channel-relay-module-5v-no-name-1.snapshot.2/4 Channel No Name Relay Parts/Jumper.SLDPRT
4-channel-relay-module-5v-no-name-1.snapshot.2/4 Channel No Name Relay Parts/Relay Body.SLDPRT
PCB_FILES/BOX_CAD/2d.DXF
PCB_FILES/BOX_CAD/2d.SLDDRW
PCB_FILES/BOX_CAD/bottom_plate.SLDPRT
PCB_FILES/BOX_CAD/side_plate.SLDPRT
PCB_FILES/BOX_CAD/side_plate2.SLDPRT
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

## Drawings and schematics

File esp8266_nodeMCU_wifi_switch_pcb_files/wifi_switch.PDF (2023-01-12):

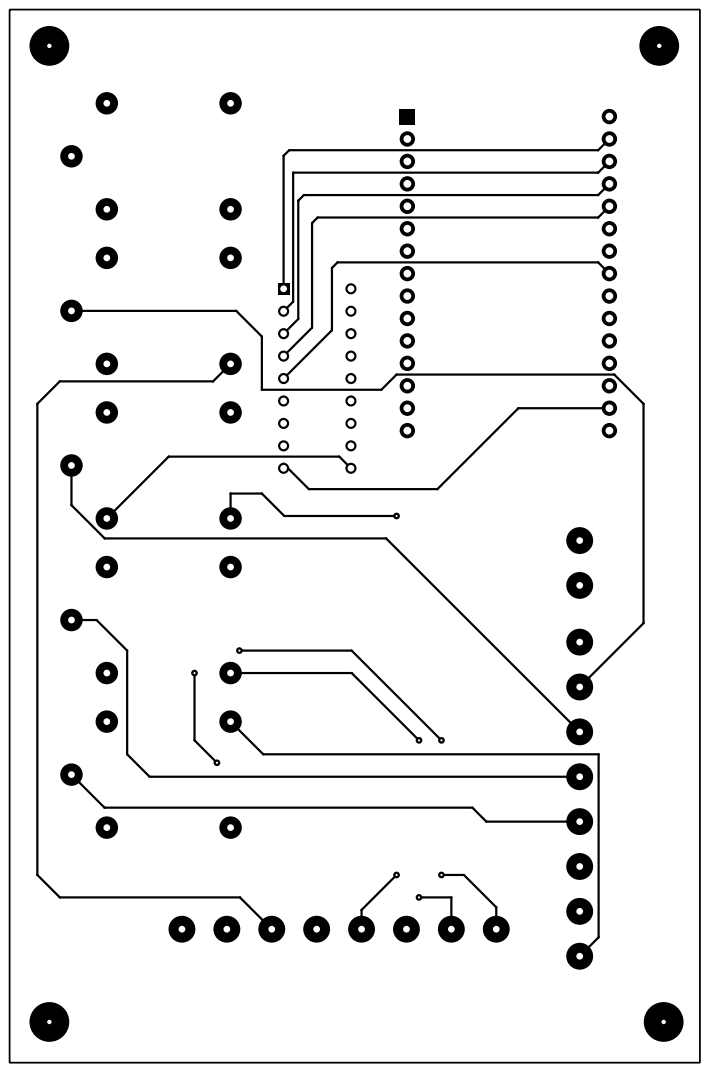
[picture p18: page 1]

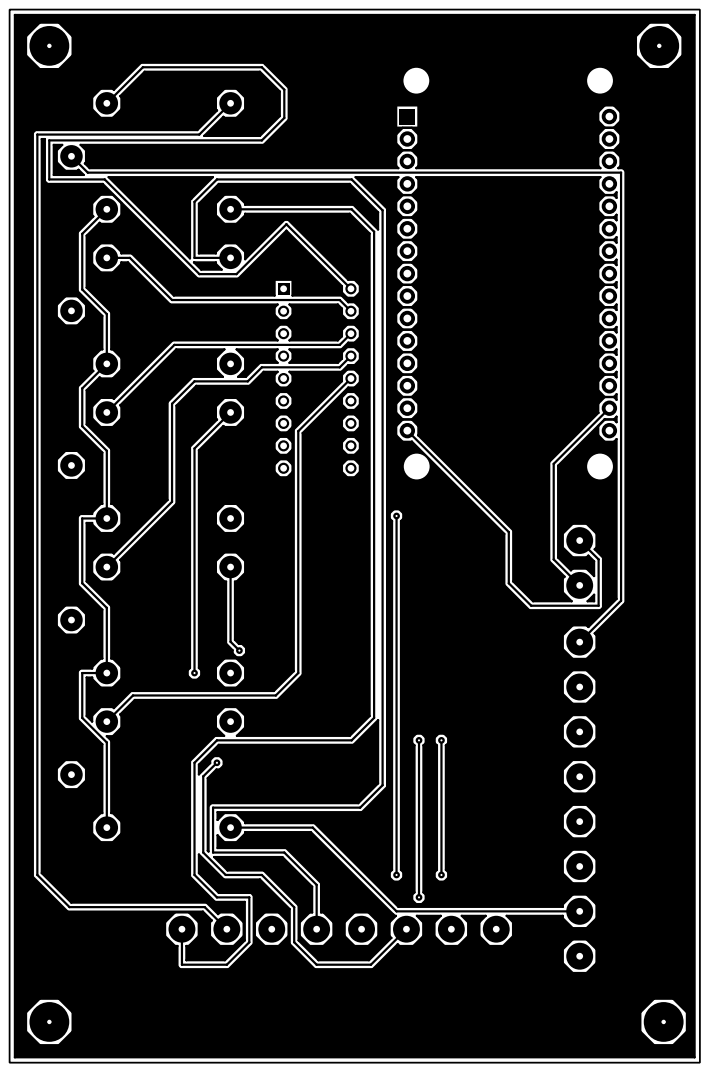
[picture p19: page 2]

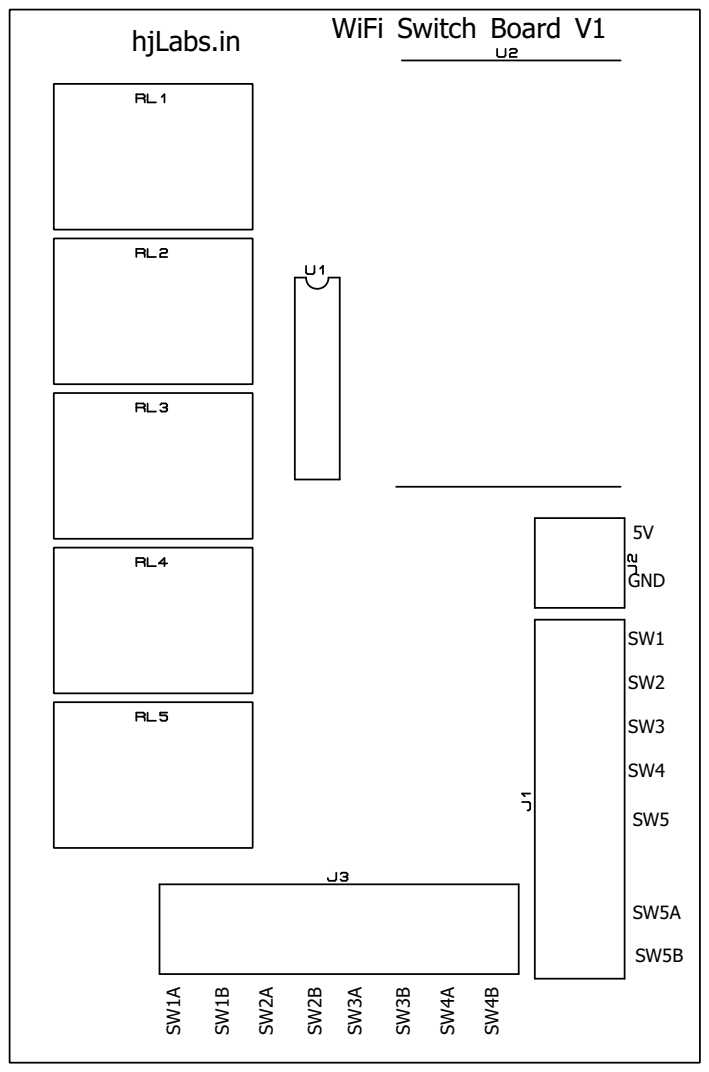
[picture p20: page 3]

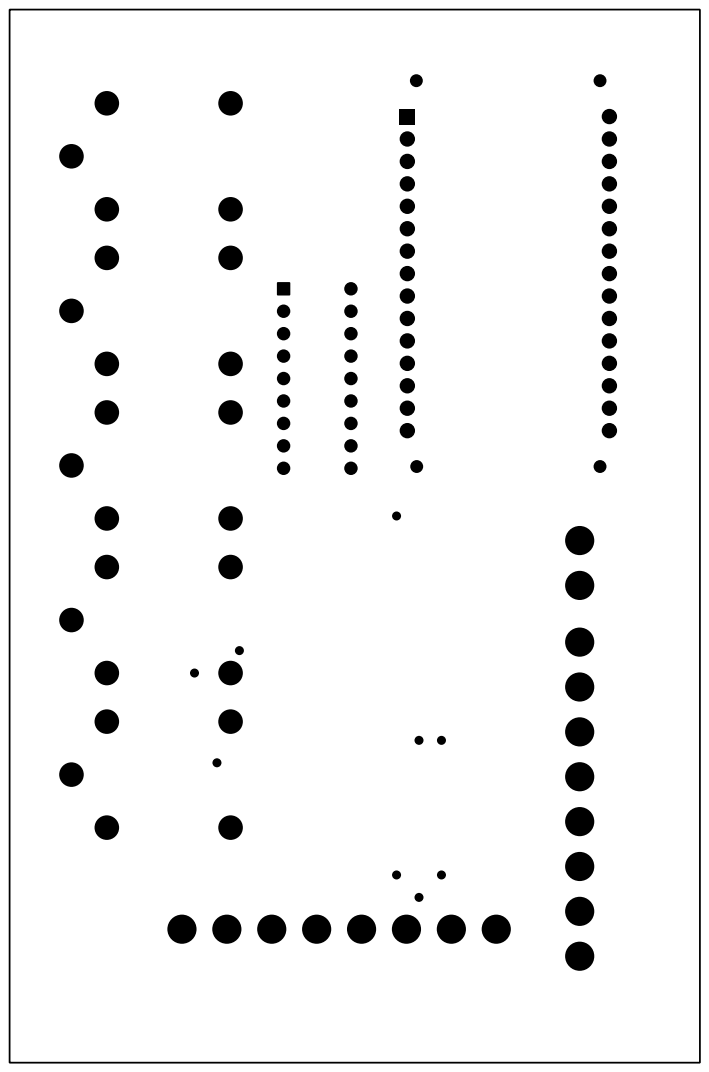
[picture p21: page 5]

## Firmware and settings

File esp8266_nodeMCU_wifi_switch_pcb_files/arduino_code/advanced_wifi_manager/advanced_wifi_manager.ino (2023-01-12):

#include <WiFiManager.h>

#define TRIGGER_PIN 0

// wifimanager can run in a blocking mode or a non blocking mode
// Be sure to know how to process loops with no delay() if using non blocking
bool wm_nonblocking = false; // change to true to use non blocking

WiFiManager wm; // global wm instance
WiFiManagerParameter custom_field; // global param ( for non blocking w params )

void setup() {
  WiFi.mode(WIFI_STA); // explicitly set mode, esp defaults to STA+AP  
  Serial.begin(115200);
  Serial.setDebugOutput(true);  
  delay(3000);
  Serial.println("\n Starting");

  pinMode(TRIGGER_PIN, INPUT);
  
  // wm.resetSettings(); // wipe settings

  if(wm_nonblocking) wm.setConfigPortalBlocking(false);

  // add a custom input field
  int customFieldLength = 40;


  new (&custom_field) WiFiManagerParameter("customfieldid", "Custom Field Label", "Custom Field Value", customFieldLength,"placeholder=\"Custom Field Placeholder\"");
  
  // test custom html input type(checkbox)
  new (&custom_field) WiFiManagerParameter("customfieldid", "Custom Field Label", "Custom Field Value", customFieldLength,"placeholder=\"Custom Field Placeholder\" type=\"checkbox\""); // custom html type
  
  // test custom html(radio)
  const char* custom_radio_str = "<br/><label for='customfieldid'>Custom Field Label</label><input type='radio' name='customfieldid' value='1' checked> One<br><input type='radio' name='customfieldid' value='2'> Two<br><input type='radio' name='customfieldid' value='3'> Three";
  new (&custom_field) WiFiManagerParameter(custom_radio_str); // custom html input
  
  wm.addParameter(&custom_field);
  wm.setSaveParamsCallback(saveParamCallback);

  // custom menu via array or vector
  // 
  // menu tokens, "wifi","wifinoscan","info","param","close","sep","erase","restart","exit" (sep is seperator) (if param is in menu, params will not show up in wifi page!)
  const char* menu[] = {"wifi","info","param","sep","restart","exit"}; 
  wm.setMenu(menu,6);
  // std::vector<const char *> menu = {"wifi","info","param","sep","restart","exit"};
  // wm.setMenu(menu);

  // set dark theme
  wm.setClass("invert");


  //set static ip
  // wm.setSTAStaticIPConfig(IPAddress(10,0,1,99), IPAddress(10,0,1,1), IPAddress(255,255,255,0)); // set static ip,gw,sn
  wm.setShowStaticFields(true); // force show static ip fields
  wm.setShowDnsFields(true);    // force show dns field always

  // wm.setConnectTimeout(20); // how long to try to connect for before continuing
  wm.setConfigPortalTimeout(30); // auto close configportal after n seconds
  // wm.setCaptivePortalEnable(false); // disable captive portal redirection
  // wm.setAPClientCheck(true); // avoid timeout if client connected to softap

  // wifi scan settings
  // wm.setRemoveDuplicateAPs(false); // do not remove duplicate ap names (true)
  // wm.setMinimumSignalQuality(20);  // set min RSSI (percentage) to show in scans, null = 8%
  // wm.setShowInfoErase(false);      // do not show erase button on info page
  // wm.setScanDispPerc(true);       // show RSSI as percentage not graph icons
  
  // wm.setBreakAfterConfig(true);   // always exit configportal even if wifi save fails

  bool res;
  res = wm.autoConnect(); // auto generated AP name from chipid
  // res = wm.autoConnect("AutoConnectAP"); // anonymous ap
  // res = wm.autoConnect("AutoConnectAP","password"); // password protected ap

  if(!res) {
    Serial.println("Failed to connect or hit timeout");
    // ESP.restart();
  } 
  else {
    //if you get here you have connected to the WiFi    
    Serial.println("connected...yeey :)");
  }
}

void checkButton(){
  // check for button press
  if ( digitalRead(TRIGGER_PIN) == LOW ) {
    // poor mans debounce/press-hold, code not ideal for production
    delay(50);
    if( digitalRead(TRIGGER_PIN) == LOW ){
      Serial.println("Button Pressed");
      // still holding button for 3000 ms, reset settings, code not ideaa for production
      delay(3000); // reset delay hold
      if( digitalRead(TRIGGER_PIN) == LOW ){
        Serial.println("Button Held");
        Serial.println("Erasing Config, restarting");
        wm.resetSettings();
        ESP.restart();
      }
      
      // start portal w delay
      Serial.println("Starting config portal");
      wm.setConfigPortalTimeout(120);
      
      if (!wm.startConfigPortal("OnDemandAP","password")) {
        Serial.println("failed to connect or hit timeout");
        delay(3000);
        // ESP.restart();
      } else {
        //if you get here you have connected to the WiFi
        Serial.println("connected...yeey :)");
      }
    }
  }
}


String getParam(String name){
  //read parameter from server, for customhmtl input
  String value;
  if(wm.server->hasArg(name)) {
    value = wm.server->arg(name);
  }
  return value;
}

void saveParamCallback(){
  Serial.println("[CALLBACK] saveParamCallback fired");
  Serial.println("PARAM customfieldid = " + getParam("customfieldid"));
}

void loop() {
  if(wm_nonblocking) wm.process(); // avoid delays() in loop when non-blocking and other long running code  
  checkButton();
  // put your main code here, to run repeatedly:
}

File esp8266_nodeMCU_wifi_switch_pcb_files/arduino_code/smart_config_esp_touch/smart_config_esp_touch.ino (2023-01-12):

#include <ESP8266WiFi.h>;

void setup() {
  Serial.begin(115200);
  delay(10);

  WiFi.mode(WIFI_AP_STA);
  delay(500);

  WiFi.beginSmartConfig();

  while (WiFi.status() != WL_CONNECTED) {
    delay(500);
    Serial.print(".");
    Serial.println(WiFi.smartConfigDone());
  }

  Serial.println("");
  Serial.println("WiFi connected");  
  Serial.println("IP address: ");
  Serial.println(WiFi.localIP());
}

int value = 0;

void loop() {

}
